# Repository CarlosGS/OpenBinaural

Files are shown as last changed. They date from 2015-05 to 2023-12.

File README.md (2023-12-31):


# OpenBinaural 3D microphone design
Low-cost 3D-printable binaural microphone.  

Project presented at [**OSHWDem 2015**](http://oshwdem.org/) (Open Source Hardware Demonstration in A Coruña, Spain) and [**Maker Faire Bilbao 2015**](http://bilbaomakerfaire.com/meet-the-makers-2015/). First featured in [**Hackaday**](http://hackaday.com/2015/06/28/3d-printing-binaural-microphones/).

Assembly instructions
--
[**Click here for the full assembly instructions**](https://github.com/carlosgs/OpenBinaural/wiki)  

Demo recordings
--
* By [Philippe Benaim](https://www.youtube.com/channel/UCL3Ne8XJYRqAHHRvmHdczcw):
 * Un tour Montgolfière [(link)](https://www.youtube.com/watch?v=H2nlUVNs7Po)
 * Château de Chenonceau Outside [(link)](https://www.youtube.com/watch?v=rT2So4uhhjw)
 * Vacances Aout 2015 [(link)](https://www.youtube.com/watch?v=p6LAYfAAe6M)
* By Carlosgs:
 * Sea shore in A Coruña, Spain [(link)](https://www.youtube.com/watch?v=49GC-DsRlKY)
* If you use the mic, please let me know, I'd love to *hear* about it! :-)

Assembled OpenBinaural microphone:  

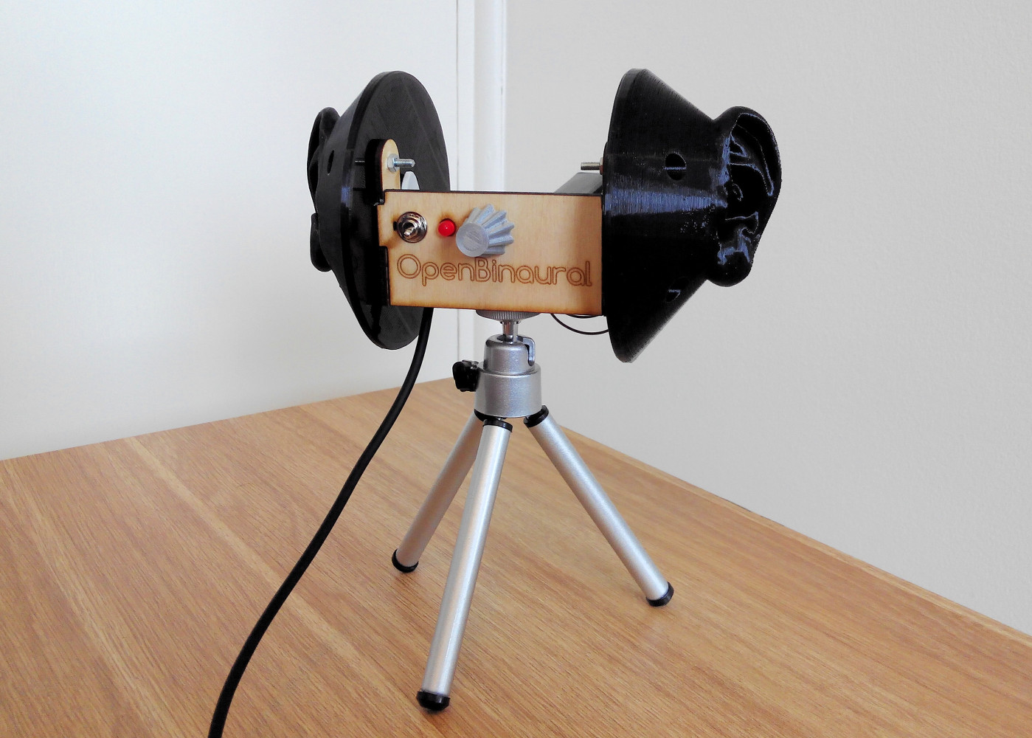
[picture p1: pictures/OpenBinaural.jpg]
  

3D-printable ears  
--
The [left](binaural_mic_left.stl) and [right](binaural_mic_right.stl) ears, and the [potentiometer knob](potentiometer_knob.stl) can be 3D-printed in PLA or ABS. Flexible materials may create more realistic effects!  
The support for the ears can be laser-cut out of 3mm plywood ([DXF file](wood_support.dxf)) or 3D printed ([STL file](wood_support_assembled_simplified.stl)).

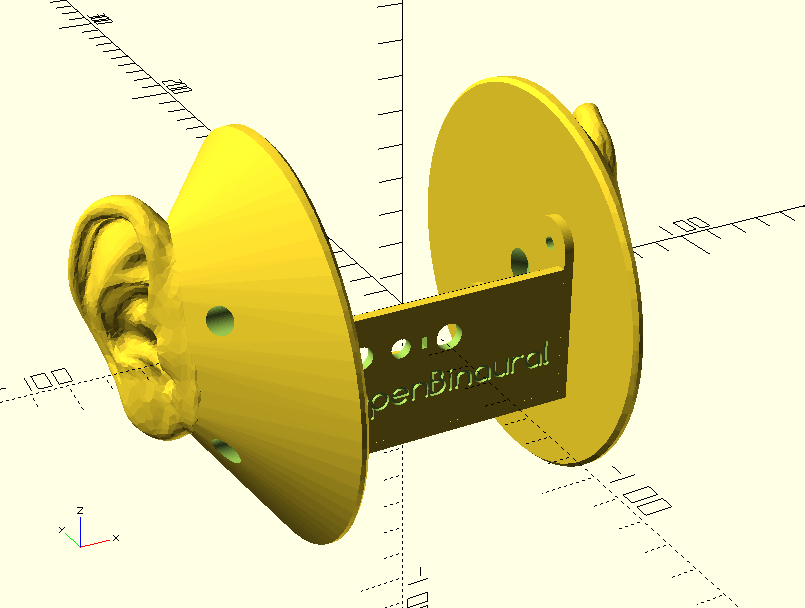
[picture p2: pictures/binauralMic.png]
  

Tripod mount detail:  
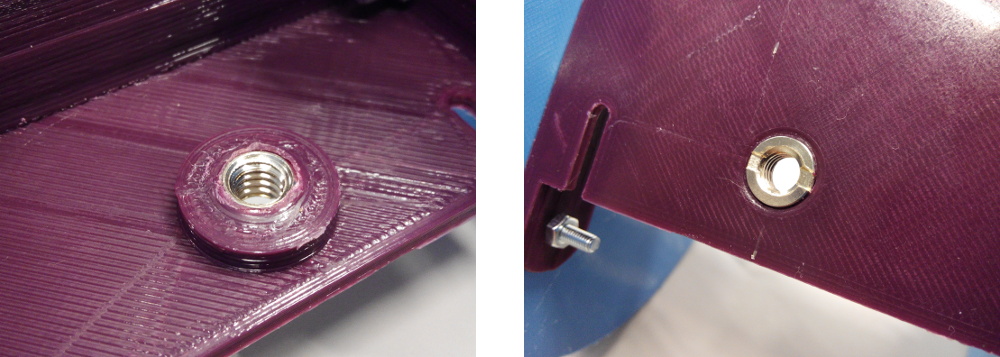
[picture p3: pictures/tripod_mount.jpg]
  
The metal insert can be found in eBay as *1/4" to 3/8" convert screw*  

Electronics  
--

**Note: The amplifier circuit is very outdated and noisy! Instead I recommend connecting the microphone capsules directly to the recorder. See [here](https://github.com/carlosgs/OpenBinaural/wiki#if-you-have-a-gopro-you-dont-need-the-amplifier-circuit) for an example.**

The KiCad sources for the electronics can be found in the [Electronics](Electronics) folder.  
Here are the [schematic](Electronics/stereo_mic_amplifier.pdf) and [layout](Electronics/pictures/stereo_mic_amplifier_layout.png).  
The Gerber files, B/W layout in PDF, and CNC gcode files can be found [here](Electronics/Gerber).  

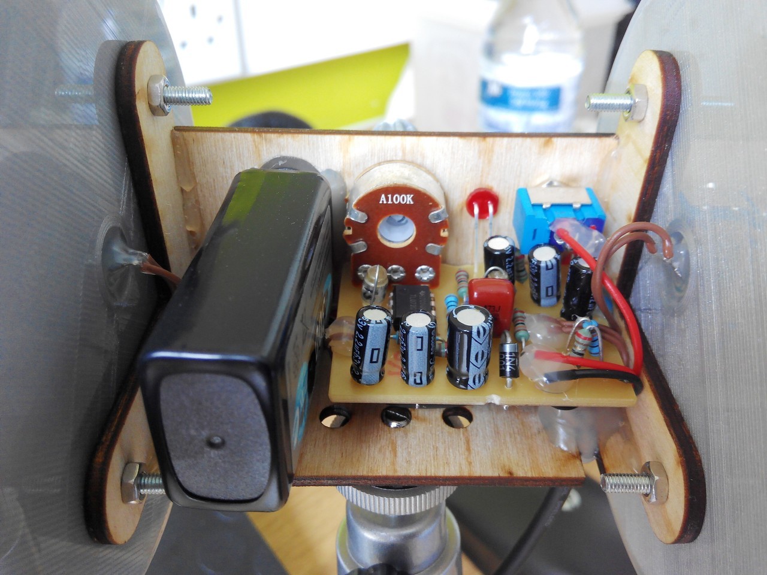
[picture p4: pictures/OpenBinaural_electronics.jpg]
  

Detailed ear canal
--
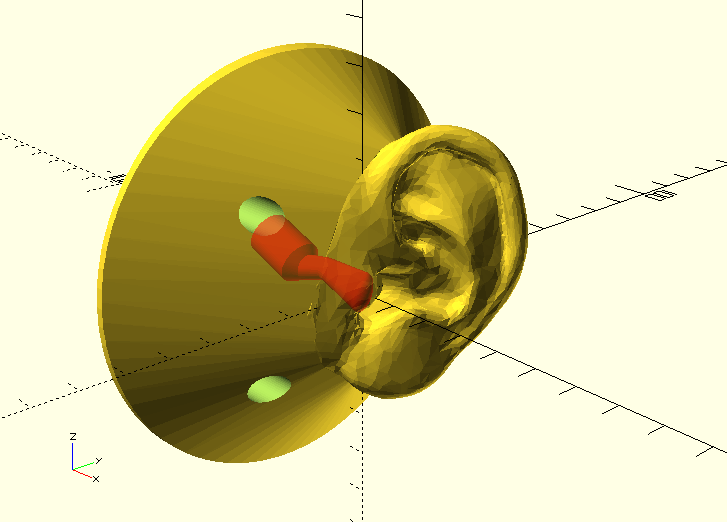
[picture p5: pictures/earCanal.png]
  
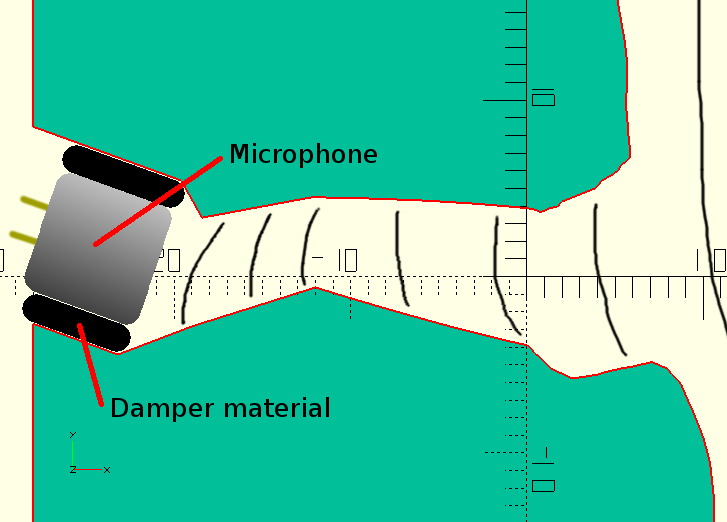
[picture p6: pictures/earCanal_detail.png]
  

Where to buy
--
I currently have no plans to sell this microphone, it has an open license so **anyone can build it or sell it** (as long as they provide attribution and publish their modifications as open too).  
Please refer to the following links if you just need a binaural microphone that works out of the box:  

- [**3Dio**](https://3diosound.com/)
- [**SR3D**](https://www.sr3d.co.uk/), [**Ebay**](https://www.ebay.co.uk/str/sr3dbinauralmicrophones)

Acknowledgments  
--
* The awesome ear model was designed by **Jonathan March**:  
<http://www.thingiverse.com/thing:499001>  
For this project, the STL was modified with [FreeCAD](http://freecadweb.org/) and [Blender](http://www.blender.org/)  

* Great inspiration was taken from [**3Dio**](http://3diosound.com/).
If you need professional quality & high-performance, check out their Free Space microphones!  

* The potentiometer knob model is derived from **John Ridley's**: <https://www.youmagine.com/designs/knob-for-potentiometer-parametric>

* I want to thank [**Imperial College Advanced Hackspace**](http://icah.org.uk/) and [**Imperial College Robotics Society**](http://icrobotics.co.uk/) for providing the infrastructure (tools, 3D printers, laser cutters & material resources) that made this project possible. The community that has grown upon them is just amazing.  

* Also thanks to Mr Rodrigo García Saura for sourcing the 1/4" to 3/8" convert screw for the tripod mount  

Author & license  
--
Author: Carlos Garcia Saura (<https://github.com/CarlosGS/>)  
License: CC-BY-SA (<http://creativecommons.org/licenses/by-sa/4.0/>)  

Please cite as:
--

Latex / Bibtex citation:

```bibtex
@misc{garciasaura2015binaural,
  author = {Garcia-Saura, Carlos},
  title = {Open Binaural 3D microphone design},
  publisher = {GitHub},
  year = {2015},
  doi = {10.5281/ZENODO.10446511},
  url = {https://doi.org/10.5281/ZENODO.10446511}
}
```

APA style citation:

- García-Saura, C. (2015). Open Binaural 3D microphone design. GitHub. https://doi.org/10.5281/ZENODO.10446511

Also check out my previous work _"3D Video with Binaural Audio"_:

- García-Saura, C. (2011). Vídeo en 3D con Sonido Binaural. Congreso del XXIV Certamen Jóvenes Investigadores INJUVE, CEULAJ Málaga. INJUVE. https://doi.org/10.5281/ZENODO.10445722

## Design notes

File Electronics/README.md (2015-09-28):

# Stereo microphone amplifier

Stereo microphone amplifier circuit with gain control.  

The circuit has been tested with the POM-5238P-R microphone capsules:  
<http://www.puiaudio.com/product-detail.aspx?categoryId=4&partnumber=POM-5238P-R>  

CNC manufacture files (gerbers, FlatCAM project & gcodes) are available in the [Gerber](Gerber) folder.  

Assembly instructions
--
[**Click here for the full assembly instructions**](https://github.com/carlosgs/OpenBinaural/wiki)  

Pictures  
--
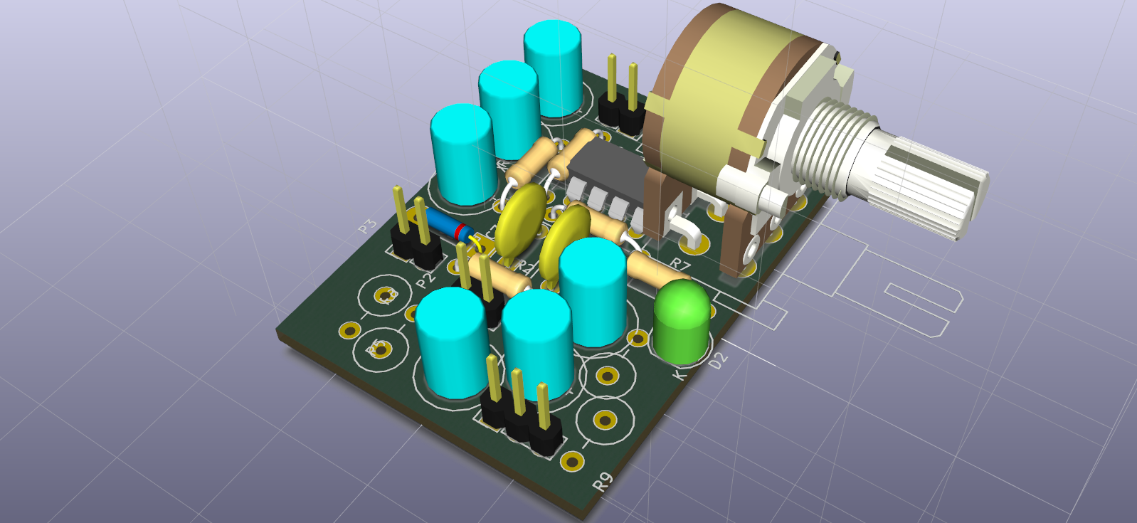
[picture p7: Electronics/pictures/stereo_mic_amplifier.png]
  
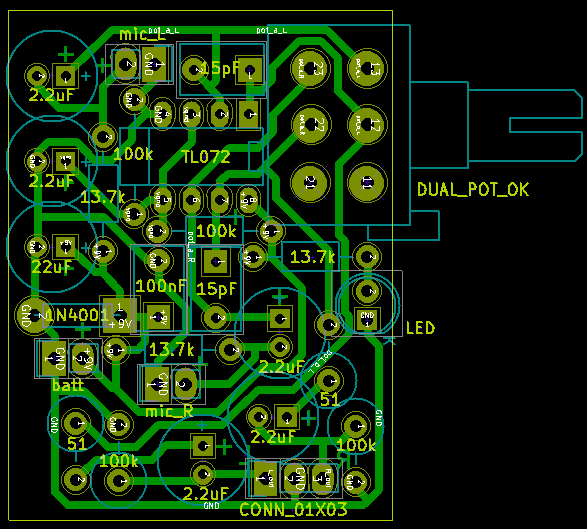
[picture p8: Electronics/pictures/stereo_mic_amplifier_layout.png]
  
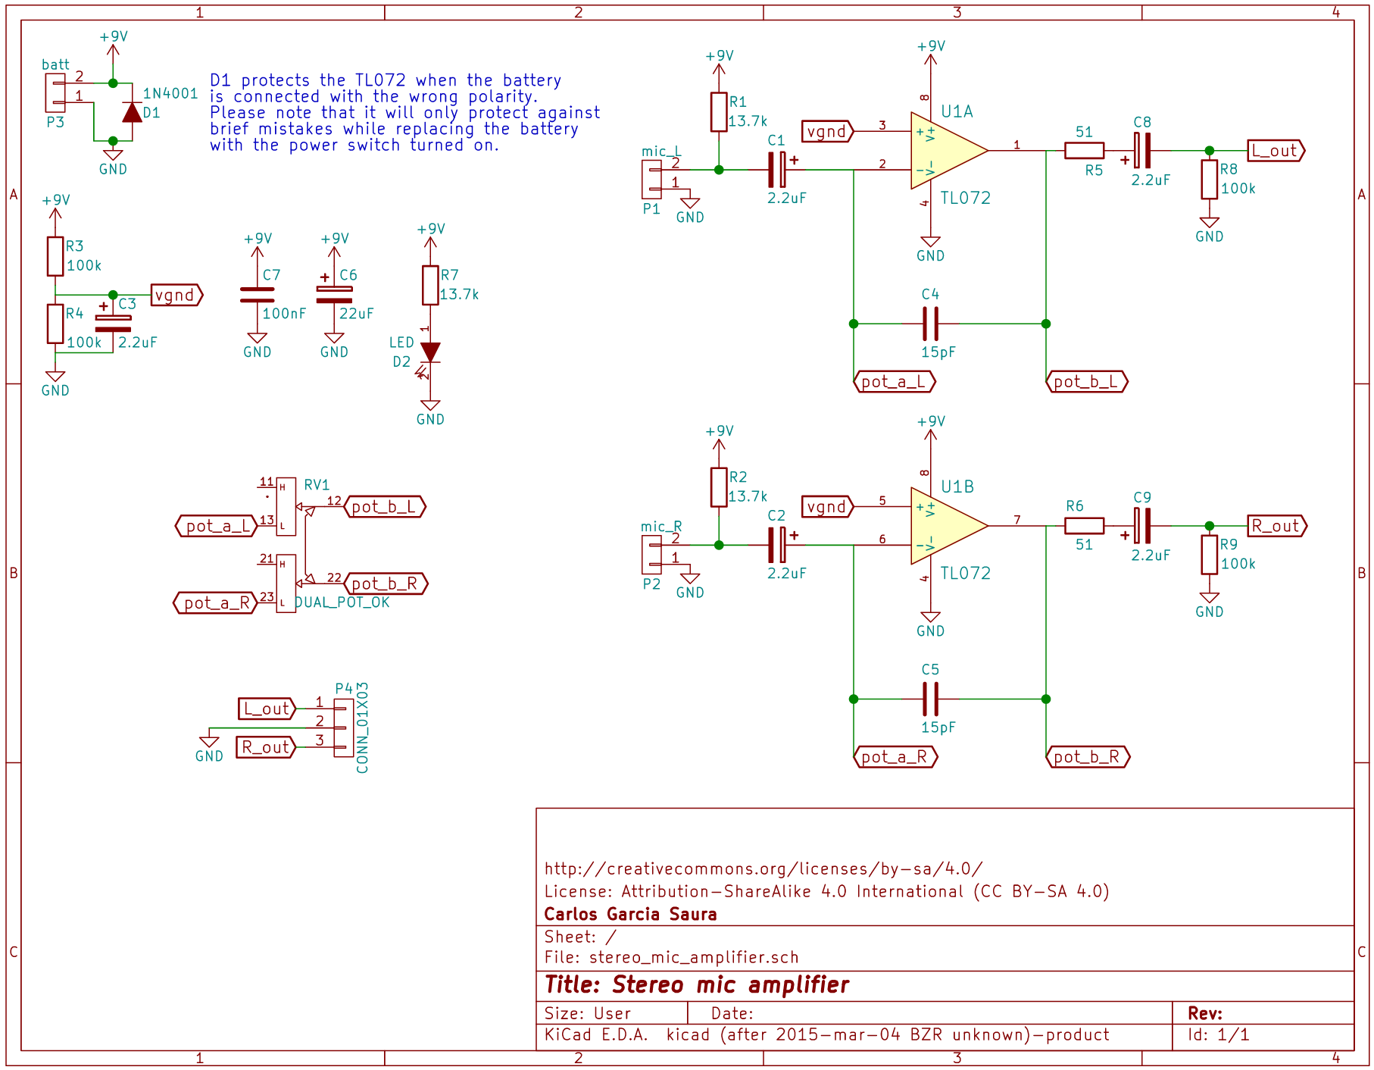
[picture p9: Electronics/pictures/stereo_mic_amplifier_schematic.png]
  
[Download the schematic in PDF](stereo_mic_amplifier.pdf)  

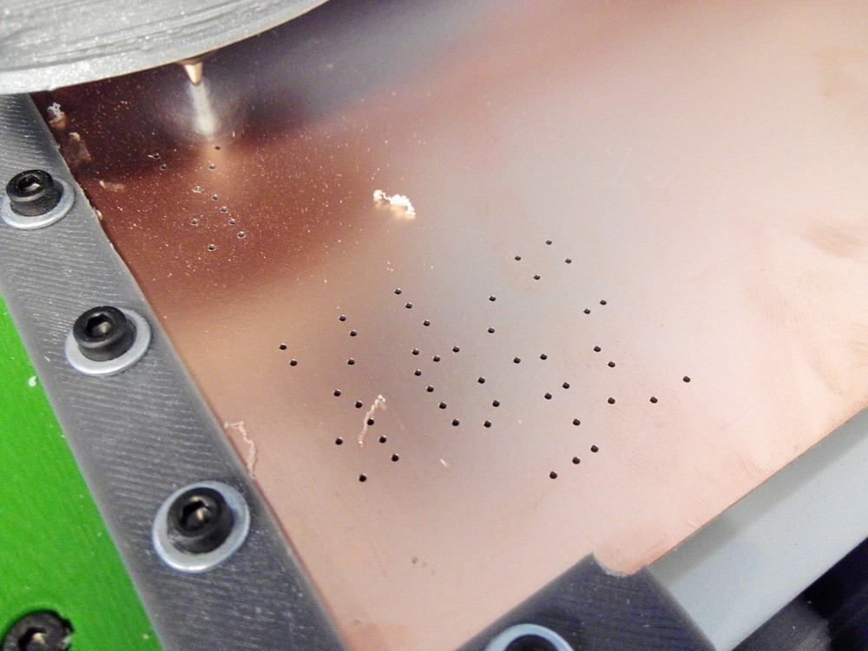
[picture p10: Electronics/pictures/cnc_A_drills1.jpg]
  
Aprox milling time for 0.8mm drill: 4 minutes  

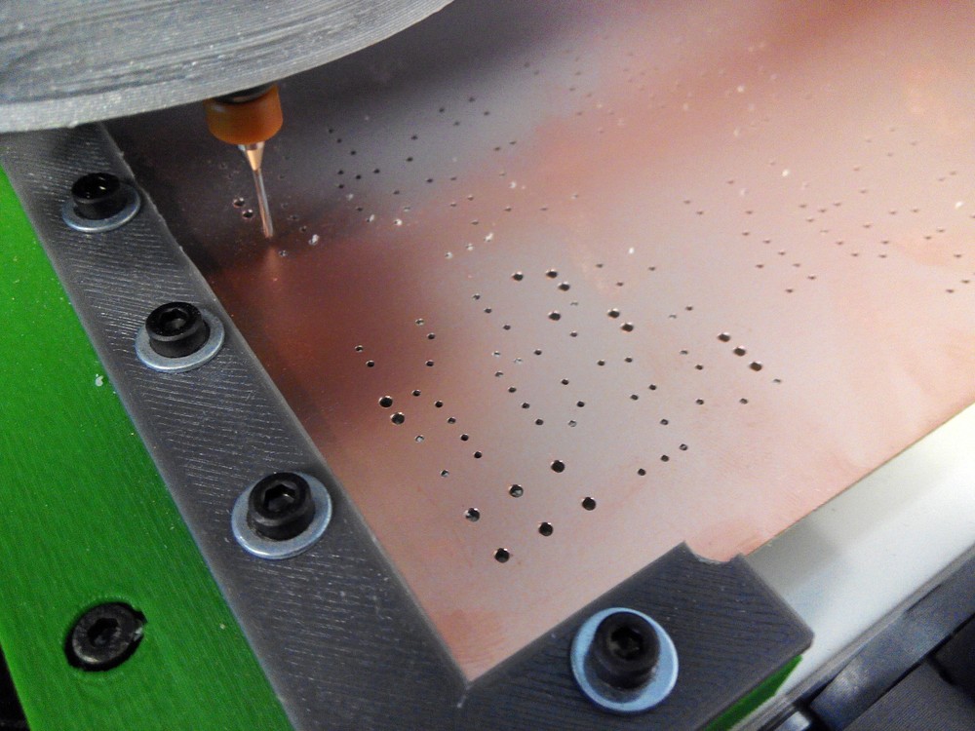
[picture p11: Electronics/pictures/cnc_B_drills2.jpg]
  
Aprox milling time for 1.2mm drill: 2 minutes  

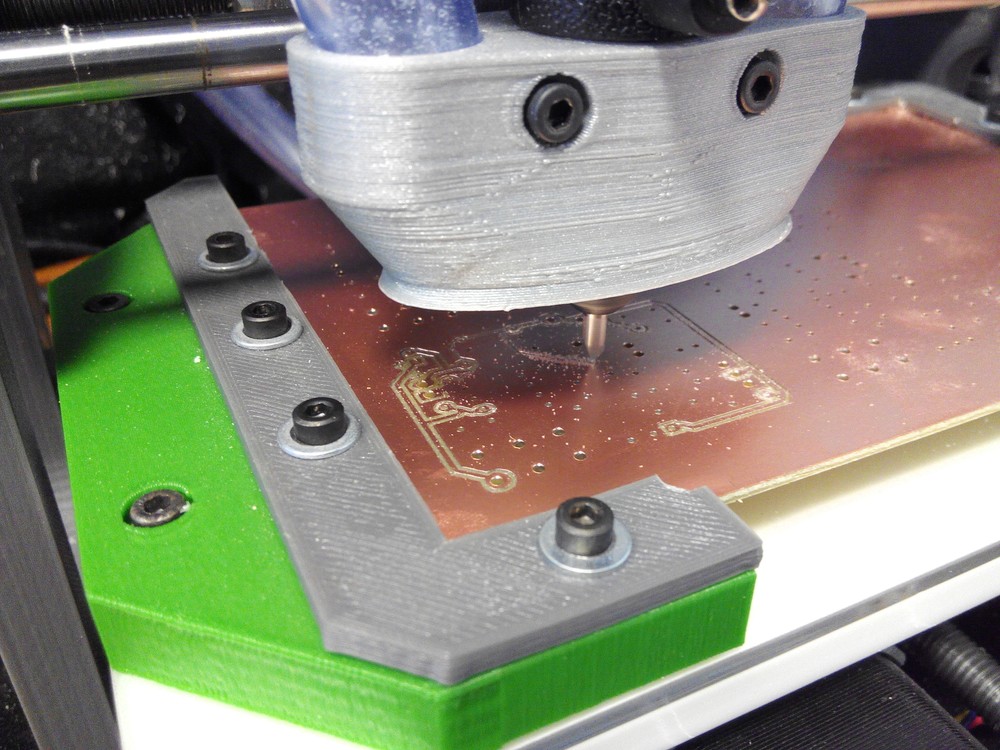
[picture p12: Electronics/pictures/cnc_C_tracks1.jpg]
  

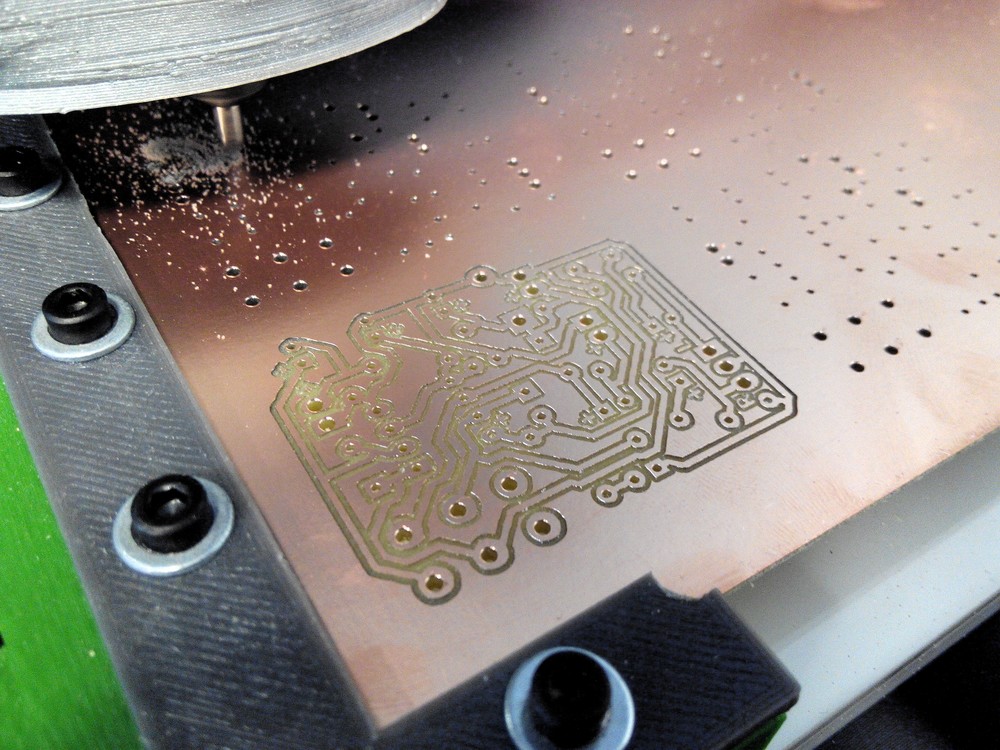
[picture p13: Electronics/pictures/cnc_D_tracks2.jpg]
  
Aprox milling time for 0.3mm copper etching: 20 minutes  

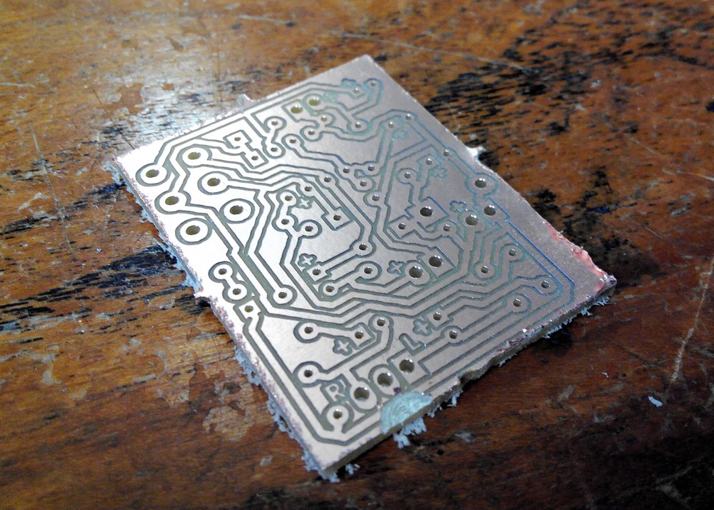
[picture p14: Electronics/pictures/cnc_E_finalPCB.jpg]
  
Aprox milling time for 2mm edges routing: 3 minutes  

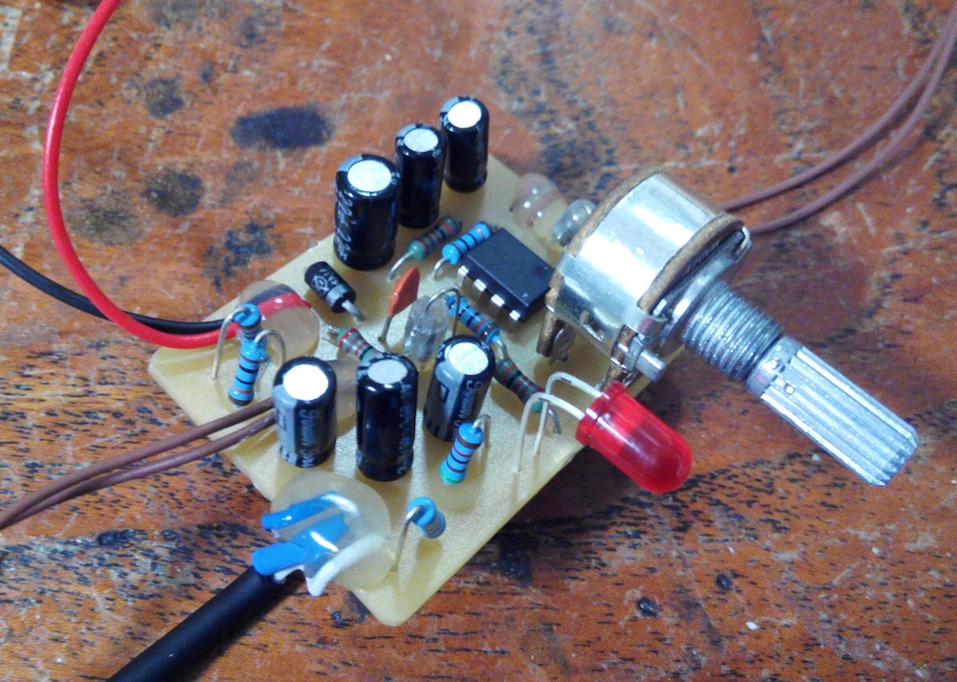
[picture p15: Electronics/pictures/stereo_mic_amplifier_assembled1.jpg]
  
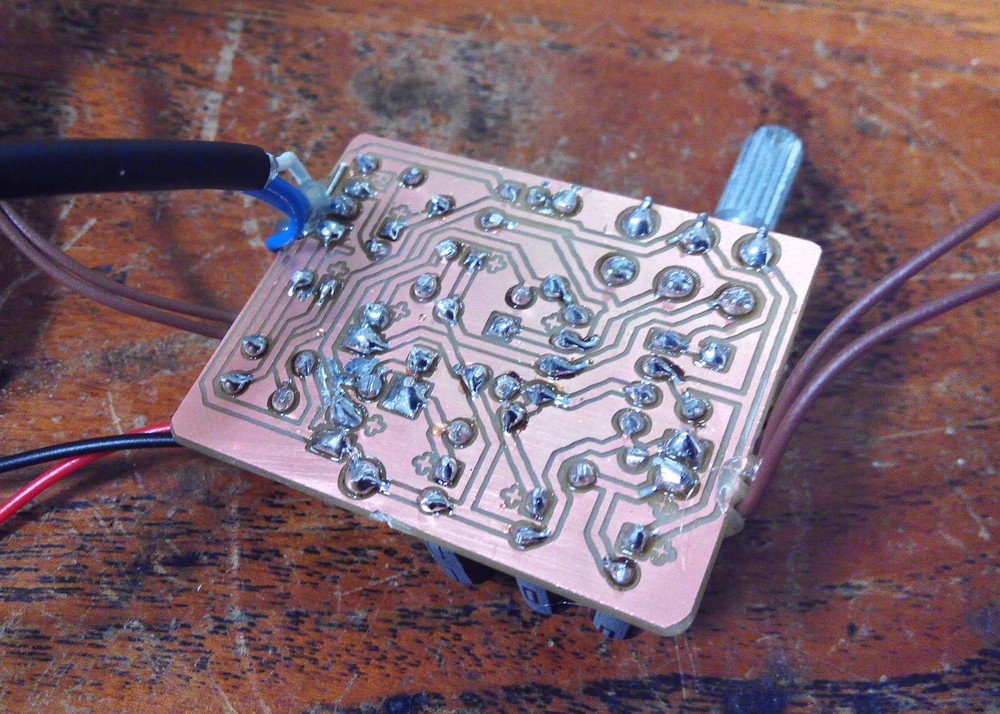
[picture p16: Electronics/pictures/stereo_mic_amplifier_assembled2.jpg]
  

Acknowledgments  
--
This circuit is a derivation from the following -very useful- Texas Instruments guide:  
[Single-Supply, Electret Microphone Preamplifier Reference Design](http://www.ti.com/tool/TIPD181) by John Caldwell  
Gain control is achieved by replacing R2 (75k) with a 100k dual potentiometer.  

Author & license  
--
Author: Carlos Garcia Saura (<http://www.carlosgs.es>)  
License: CC-BY-SA (<http://creativecommons.org/licenses/by-sa/4.0/>)

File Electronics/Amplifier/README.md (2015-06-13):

The schematic, layout & cnc manufacture files can be found in the <Amplifier> folder.  

Using the TI example application as a base, we made a stereo circuit and control the gain by replacing R2 (75k) with a 100k dual potentiometer.

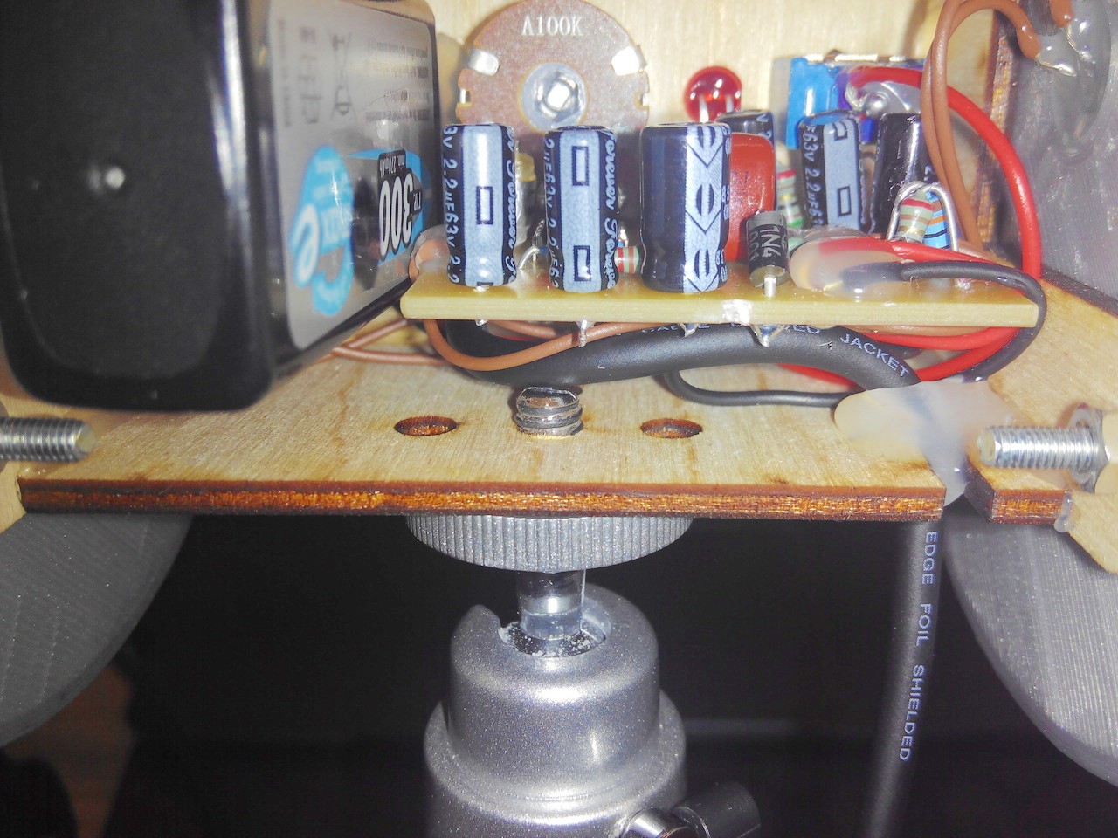
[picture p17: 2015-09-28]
pictures/OpenBinaural_electronics_2.jpg

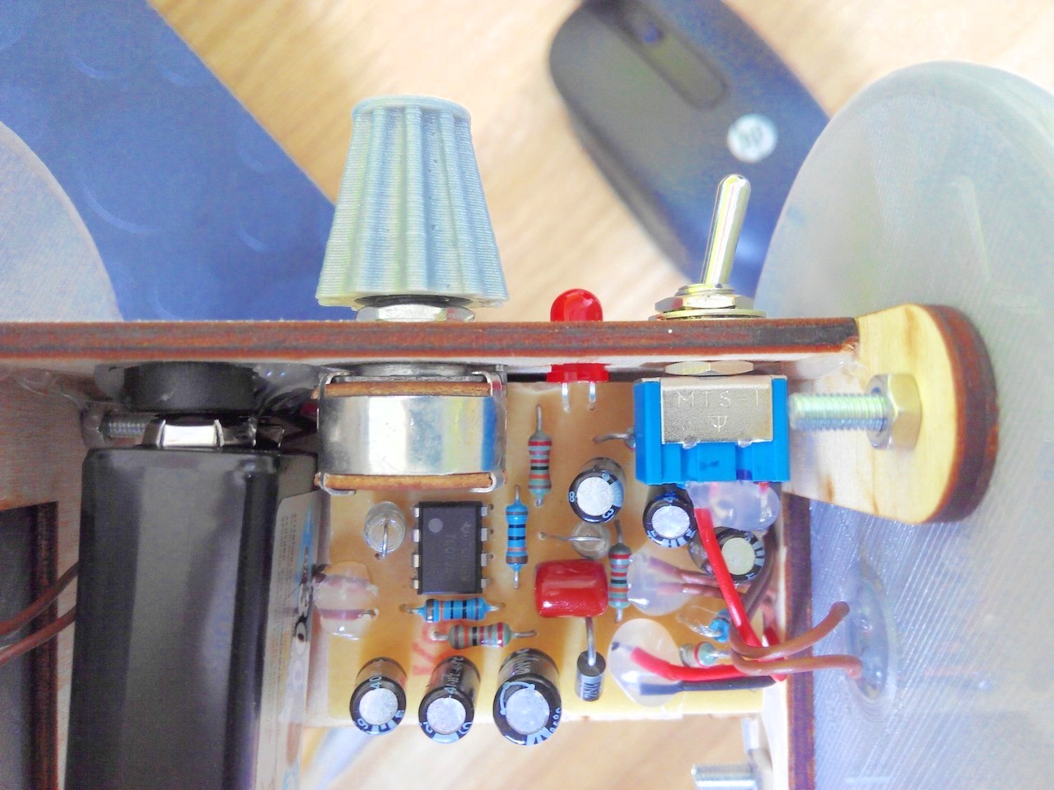
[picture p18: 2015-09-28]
pictures/OpenBinaural_electronics_3.jpg

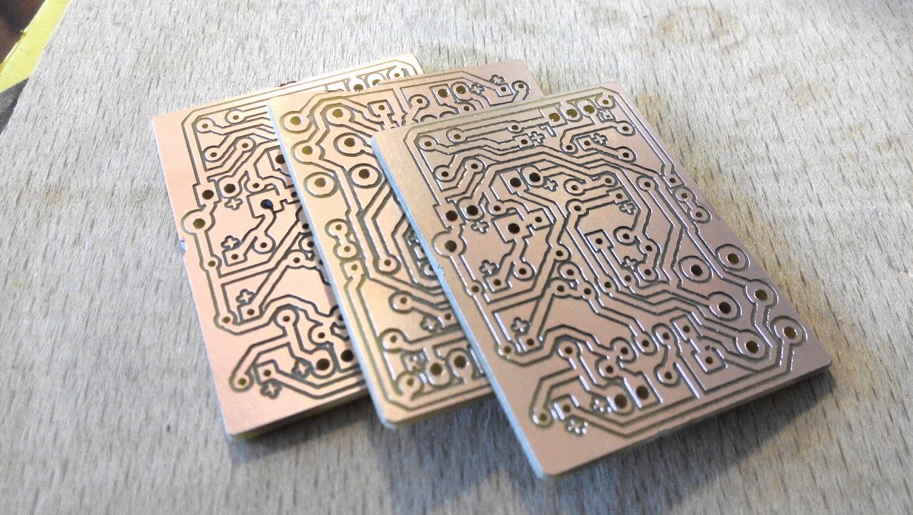
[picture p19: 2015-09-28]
Electronics/pictures/stereo_mic_amp_pcbs.jpg

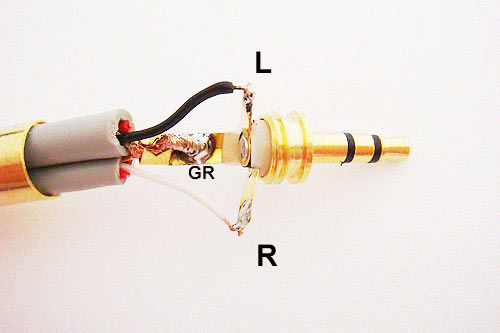
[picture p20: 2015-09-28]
Electronics/pictures/jack_connector.jpg

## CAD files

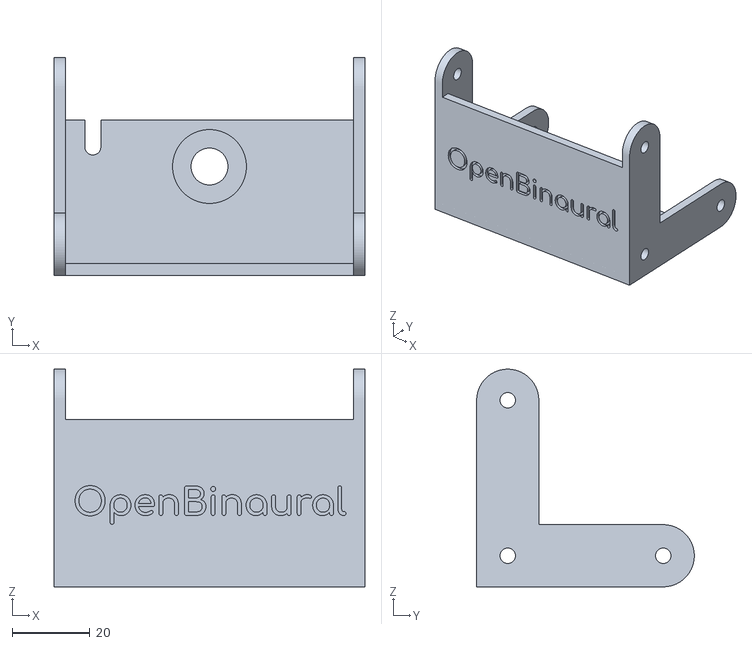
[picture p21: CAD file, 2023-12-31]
wood_support_assembled_simplified.stl
80.0 x 56.0 x 56.0

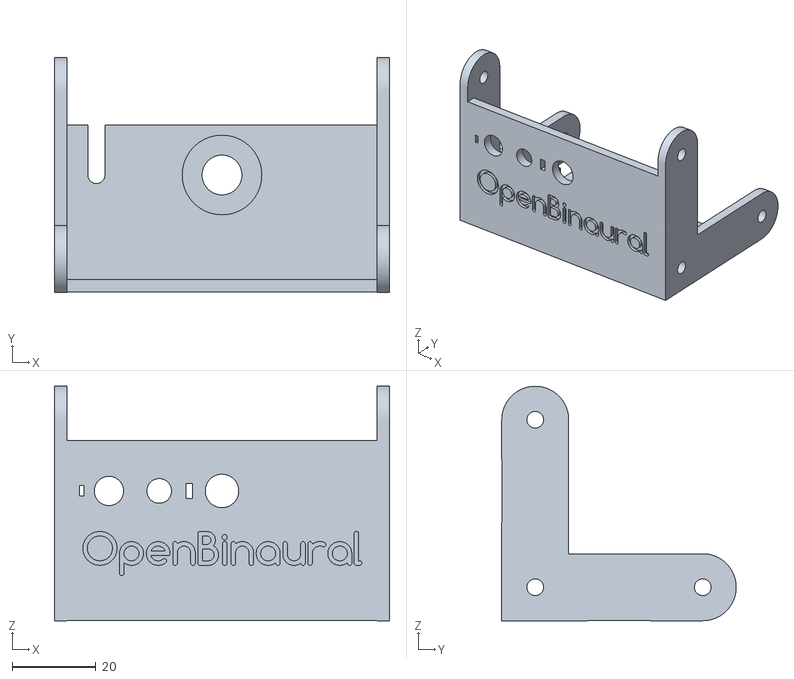
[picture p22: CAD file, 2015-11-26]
wood_support_assembled.stl
80.0 x 56.0 x 56.0

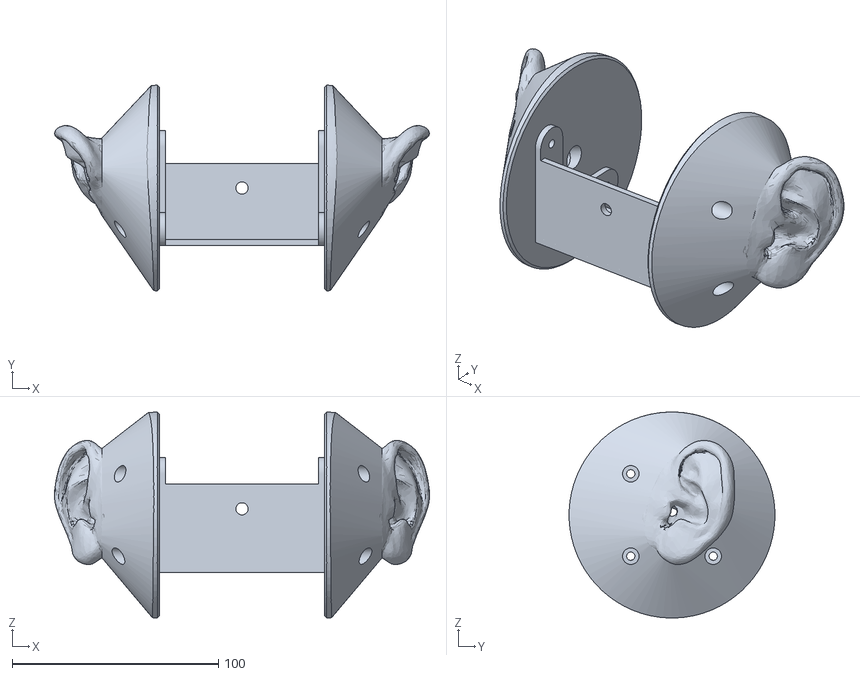
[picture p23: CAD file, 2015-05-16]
binaural_mic_assembled.stl
182.0 x 99.8 x 99.9

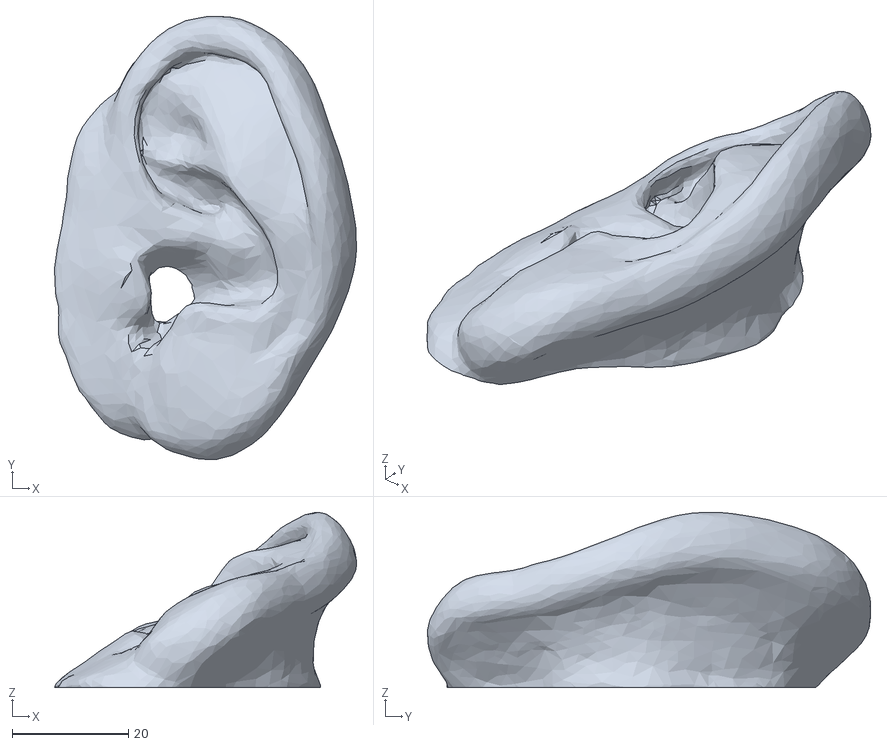
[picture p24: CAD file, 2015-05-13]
source_code/ear_left.stl
52.0 x 76.2 x 30.2

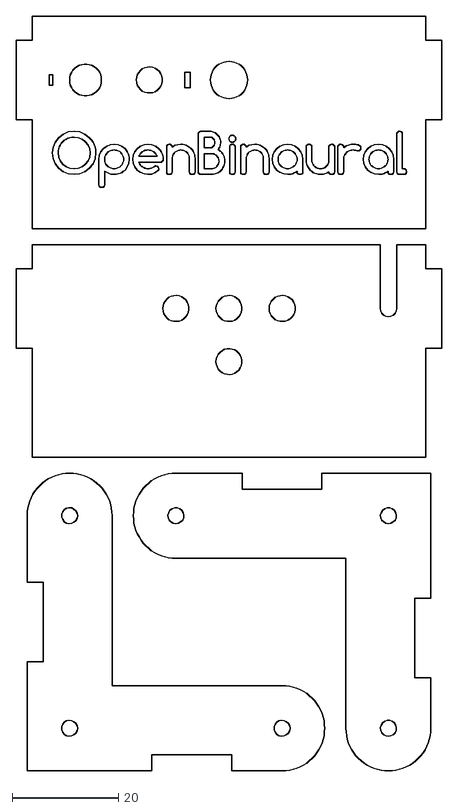
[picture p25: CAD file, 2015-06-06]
without_metal_insert/wood_support.dxf
80.0 x 142.0

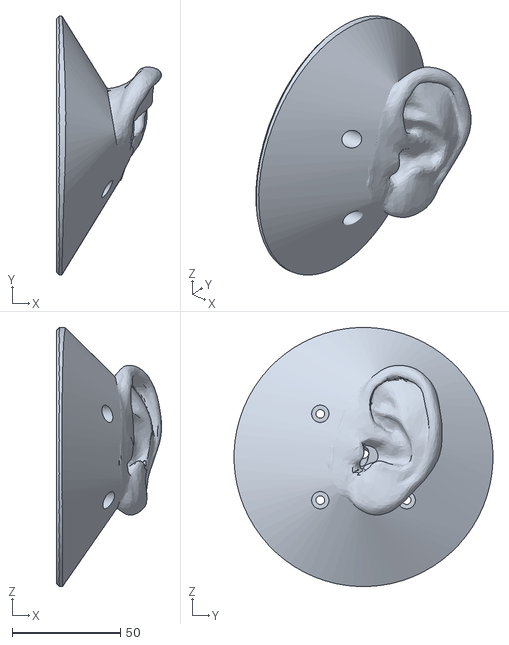
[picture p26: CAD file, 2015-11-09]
binaural_mic_left.stl
48.6 x 119.8 x 119.9

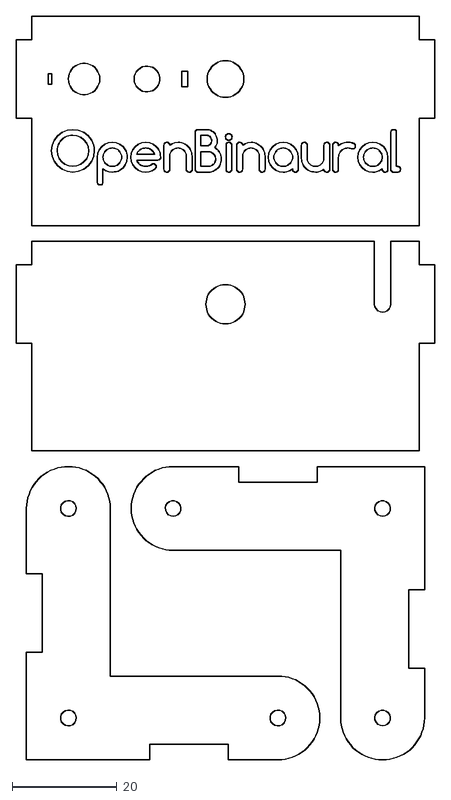
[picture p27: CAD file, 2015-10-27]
wood_support.dxf
80.0 x 142.0

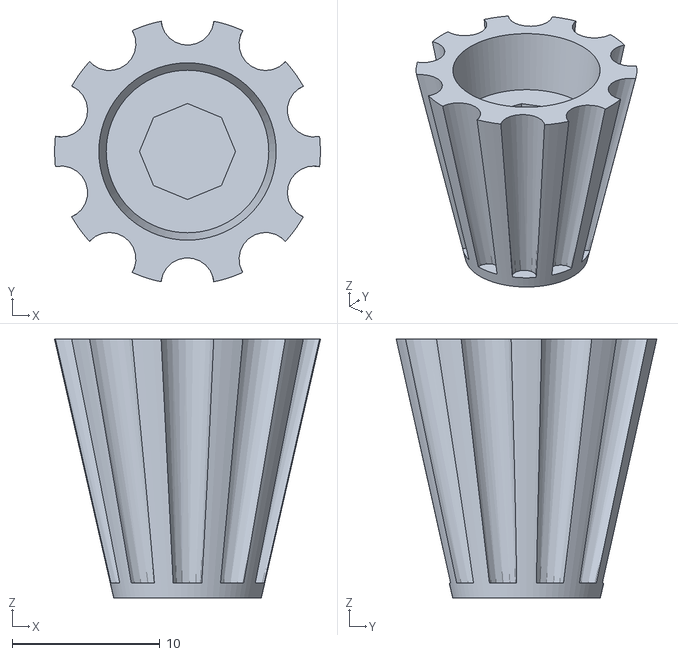
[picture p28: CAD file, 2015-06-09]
potentiometer_knob.stl
18.0 x 17.6 x 17.5

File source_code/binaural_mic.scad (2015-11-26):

// 3D-printable Binaural Microphone
//
// by Carlos Garcia Saura (http://www.carlosgs.es)
// License: CC-BY-SA (http://creativecommons.org/licenses/by-sa/4.0/)
//
// The awesome ear model was designed by Jonathan March
// http://www.thingiverse.com/thing:499001
// http://professorgreenscreen.com/


// Increase the resolution of default shapes
$fa = 5; // Minimum angle for fragments [degrees]
$fs = 0.5; // Minimum fragment size [mm]

ear_rotation = -15;
ear_vertical_rotation = 10;

ear_base_diameter = 120;
ear_canal_len_1 = 12;
ear_canal_len_2 = 8;
ear_canal_diam_1 = 5;
ear_canal_diam_2 = 6;
ear_canal_bump_height = 2;

mic_diam = 11;
mic_len = 8;
mic_transition_len = 1.5;



screw_head_diam = 8;
screw_diam = 4;
screw_holder_thickness = 5;

screw_separation = 40;

ear_scale = 68/73.54;

ear_separation = 136;



tripod_hole_diam = 9.5;// Use 5.9 for self-tapping tripod version

wood_thickness = 3;


wood_radius = screw_head_diam/2 + 4;

font = "Comfortaa:style=Bold";
brand = "OpenBinaural";
letter_size = 7.5;



ear_base_thickness = ear_canal_len_1 + ear_canal_len_2 + mic_len;
ear_base_separation = ear_separation-ear_base_thickness*2;
wood_length = ear_base_separation;


module screw_hole() {
    rotate([0,90,0]) cylinder(r=screw_diam/2,h=ear_base_thickness);
    translate([screw_holder_thickness,0,0])
        rotate([0,90,0]) cylinder(r=screw_head_diam/2,h=ear_base_thickness-screw_holder_thickness);
}

module ear_left() {
    rotate([0,90,0])
        rotate([0,0,90+3+ear_rotation])
            scale(ear_scale)
                translate([8,10,-3.01])
                    import("ear_left.stl");
}



module ear_left_full() {
    difference() {
        union() {
            rotate([0,0,ear_vertical_rotation]) ear_left();
            intersection() {
                rotate([0,-90,0])
                    hull() {
                    rotate([ear_vertical_rotation,0,0]) linear_extrude(height=0.01,center=true)
                        projection(cut=true)
                            rotate([0,90,0]) ear_left();
                    translate([0,0,ear_base_thickness])
                        cylinder(r=ear_base_diameter/2+4,h=0.01,center=true);
                    }
                // Define the ear circular base
                translate([-ear_base_thickness,0,0])
                    sphere(r=ear_base_diameter/2);
                // Bevel
                translate([-ear_base_thickness+ear_base_diameter/2,0,0])
                    sphere(r=ear_base_diameter/2+24);
            }
        }
        
        // Ear canal
        difference() {
            union(){
                // Curved inner ear
                //translate([0,2,0.5])
                //    scale([0.5,1,1])
                //        sphere(r=8/2);
                hull() {
                    rotate([ear_rotation,0,0])
                        scale([0.5,0.5,1])
                            sphere(r=9/2);
                    translate([-ear_canal_len_1,0,ear_canal_bump_height])
                        sphere(r=ear_canal_diam_1/2);
                }
                hull() {
                    translate([-ear_canal_len_1,0,ear_canal_bump_height])
                        sphere(r=ear_canal_diam_1/2);
                    translate([-ear_canal_len_1-ear_canal_len_2,0,0])
                        sphere(r=ear_canal_diam_2/2);
                }
                translate([-ear_canal_len_1-ear_canal_len_2,0,0])
                        rotate([0,20,0]) {
                            // Transition
                            hull() {
                                sphere(r=ear_canal_diam_2/2);
                                translate([-mic_transition_len,0,0])
                                    rotate([0,90,0]) cylinder(r=mic_diam/2,h=0.01);
                            }
                            // Hole for the microphone
                            translate([-mic_transition_len,0,0])
                                rotate([0,-90,0]) cylinder(r=mic_diam/2, h=mic_len*1.5);
                            // Bevel
                            //translate([-mic_len,0,0])
                            //    rotate([0,-20,0])
                            //        translate([-3,0,0])
                            //            sphere(r=mic_diam/2+1.5);
                        }
            }
            // Bump to limit microphone depth
            //translate([-ear_canal_len_1-ear_canal_len_2,0,mic_diam/2+0.3])
            //    rotate([90,0,0]) cylinder(r=1.5/2,h=mic_diam,center=true);
        }
        
        translate([-ear_base_thickness-0.1,0,0]) {
            translate([0,-screw_separation/2,screw_separation/2])
                screw_hole();
            translate([0,-screw_separation/2,-screw_separation/2])
                screw_hole();
            translate([0,screw_separation/2,-screw_separation/2])
                screw_hole();
        }
    }
}

module ear_right_full() {
    mirror([1,0,0])
        ear_left_full();
}






// Draw the canal section
//!projection(cut=true) rotate([-90,0,0]) ear_left_full();

// Draw the head (assuming it is a sphere)
//#sphere(r=140/2);

translate([ear_separation/2,0,0])
    ear_left_full();
translate([-ear_separation/2,0,0])
    ear_right_full();






// Wood parts

module wood_support_left(laser_cutter_offset=0) {
    translate([ear_base_separation/2,0,0])
        rotate([0,-90,0])
            difference() {
                union() {
                    hull() {
                        translate([screw_separation/2,-screw_separation/2,0])
                            cylinder(r=wood_radius,h=wood_thickness);
                        translate([-screw_separation/2,-screw_separation/2,wood_thickness/2])
                                cube([wood_radius*2,wood_radius*2,wood_thickness],center=true);
                    }
                    hull() {
                        translate([-screw_separation/2,-screw_separation/2,wood_thickness/2])
                                cube([wood_radius*2,wood_radius*2,wood_thickness],center=true);
                        translate([-screw_separation/2,screw_separation/2,0])
                                cylinder(r=wood_radius,h=wood_thickness);
                    }
                }
                // Screw holes
                translate([screw_separation/2,-screw_separation/2,0])
                    cylinder(r=screw_diam/2-laser_cutter_offset,h=wood_thickness*4,center=true);
                translate([-screw_separation/2,-screw_separation/2,0])
                    cylinder(r=screw_diam/2-laser_cutter_offset,h=wood_thickness*4,center=true);
                translate([-screw_separation/2,screw_separation/2,0])
                    cylinder(r=screw_diam/2-laser_cutter_offset,h=wood_thickness*4,center=true);
                // Wood "interlock" slots
                translate([wood_thickness,-screw_separation/2-wood_radius,0])
                    cube([15,wood_thickness*2,wood_thickness*2],center=true);
                translate([-screw_separation/2-wood_radius,0,0])
                    cube([wood_thickness*2,15,wood_thickness*2],center=true);
            }
}

module wood_support_right(laser_cutter_offset=0) {
    mirror([1,0,0])
        wood_support_left(laser_cutter_offset);
}
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

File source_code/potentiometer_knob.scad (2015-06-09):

// Based on:
// https://www.youmagine.com/designs/knob-for-potentiometer-parametric
// By John Ridley

// Increase the resolution of default shapes
$fa = 5; // Minimum angle for fragments [degrees]
$fs = 0.5; // Minimum fragment size [mm]

od = 18;
odt = 10;
mainh = 0;
th = 17.5-mainh;

// knurling
kd = 7/2;
kn = 10;

shaftd = 6.5;

rotate([180,0,0])
difference()
{
    translate([0,0,0.01])
	union()
	{
		cylinder(d=od, h=mainh);
		translate([0,0,mainh])
		cylinder(d1=od, d2=odt, h=th);
	}

	// knurling
	for (x=[0:kn])
        rotate([0,0,x * (360/kn)])
            translate([0,od/2,0])
                hull() {
                    //rotate([10,0,0]) cylinder(d1=kd, d2=kd, h=mainh+th-1);
                    cylinder(d=2*od/kn, h=0.01);
                    translate([0,(odt-od)/2,mainh+th-1])
                        cylinder(d=2*odt/kn, h=0.01);
                }

	// shaft hole
	cylinder(d=shaftd, h=mainh+th - 1.5, $fn = 8);

	// relief at bottom
	cylinder(d1=12,d2=od - kd*2, h=5);

}

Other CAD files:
without_metal_insert/wood_support_assembled.stl
binaural_mic_right.stl
source_code/binaural_mic_simplified.scad

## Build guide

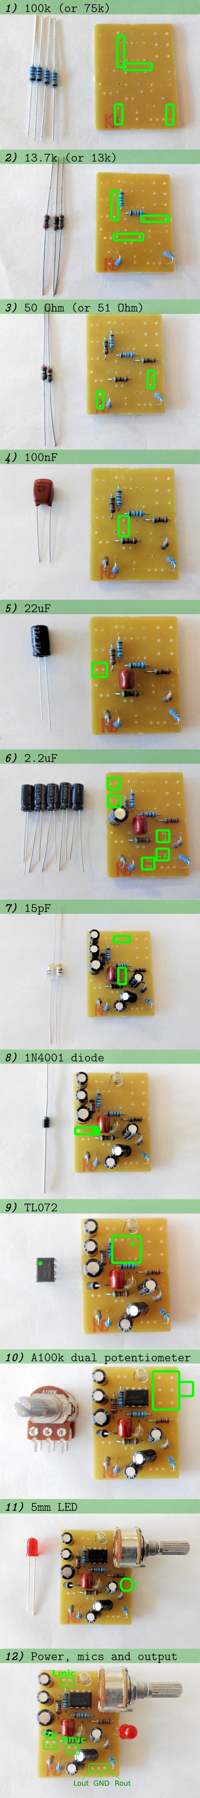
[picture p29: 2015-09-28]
Electronics/pictures/stereo_mic_amplifier_assembly_steps.jpg

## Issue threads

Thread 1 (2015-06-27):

Tripod support is not robust enough

carlosgs, 2015-06-27:
Could we have a metal insert that doesn't wear out as fast as the wood?
Maybe with a standard nut with the tripod screw diameter?

carlosgs, 2015-11-10:
Latest version includes the metal insert (though there is no solution yet for the laser cutted parts).

Closed 2015-11-10.

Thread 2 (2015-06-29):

The diodes are reversed in the schematic

carlosgs, 2015-06-29:
TO-DO: Update the schematic (include a note explaining the power supply short-circuit protection)

Thanks go to Florian for spotting it!!

"Hi,
I saw your binaural microphone project on Hackaday and had a look at your
amplifier schematic.
It seems that the diodes D1 and D2 are connected in the wrong orientation,
the supply is shorted over D1 and the Power LED D2 will not light up.
(https://github.com/carlosgs/OpenBinaural/blob/master/Electronics/stereo_mic_amplifier.pdf)
Some months ago the KICAD guys switched their diode pin numbering in the
libraries, maybe you have used an older schematic with these new library
symbols?
And I don't understand the placement of D1, you want to just short the power
supply lines over the diode if the polarity is wrong?
Regards
Florian"

Closed 2015-07-29.

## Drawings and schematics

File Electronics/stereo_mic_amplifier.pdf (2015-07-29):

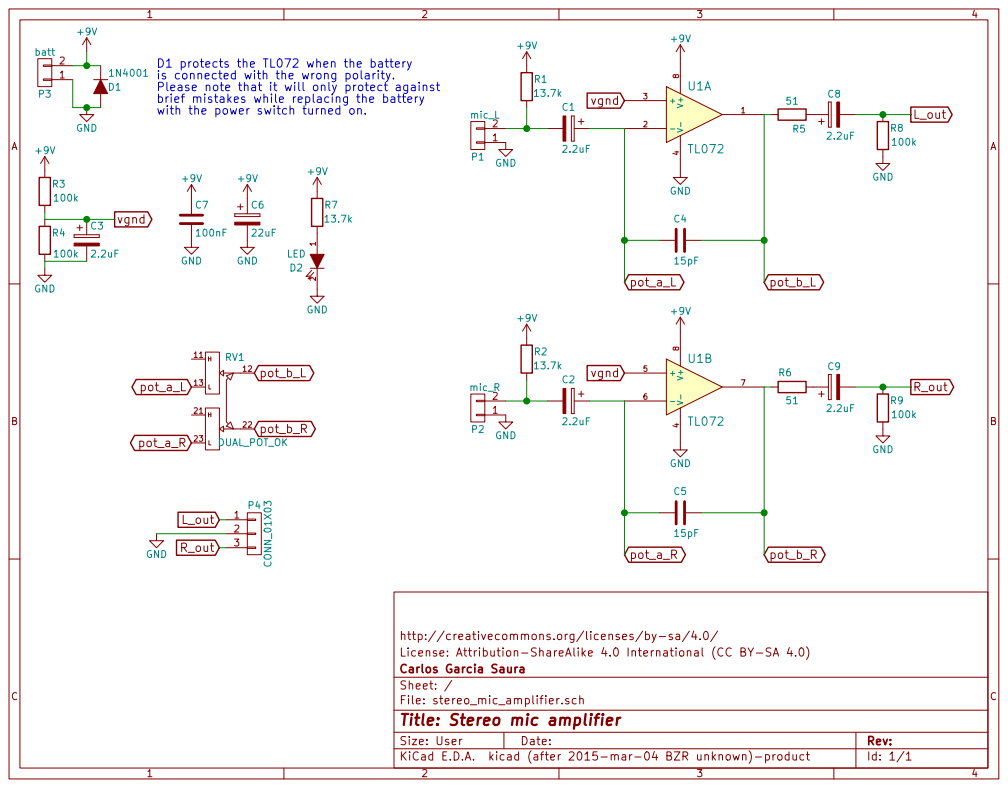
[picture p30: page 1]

is connected with the wrong polarity.
Please note that it will only protect against
brief mistakes while replacing the battery
with the power switch turned on.

License: Attribution-ShareAlike 4.0 International (CC BY-SA 4.0)
File: stereo_mic_amplifier.sch Sheet: / Carlos Garcia Saura

Id: 1/1 Title: Stereo mic amplifier

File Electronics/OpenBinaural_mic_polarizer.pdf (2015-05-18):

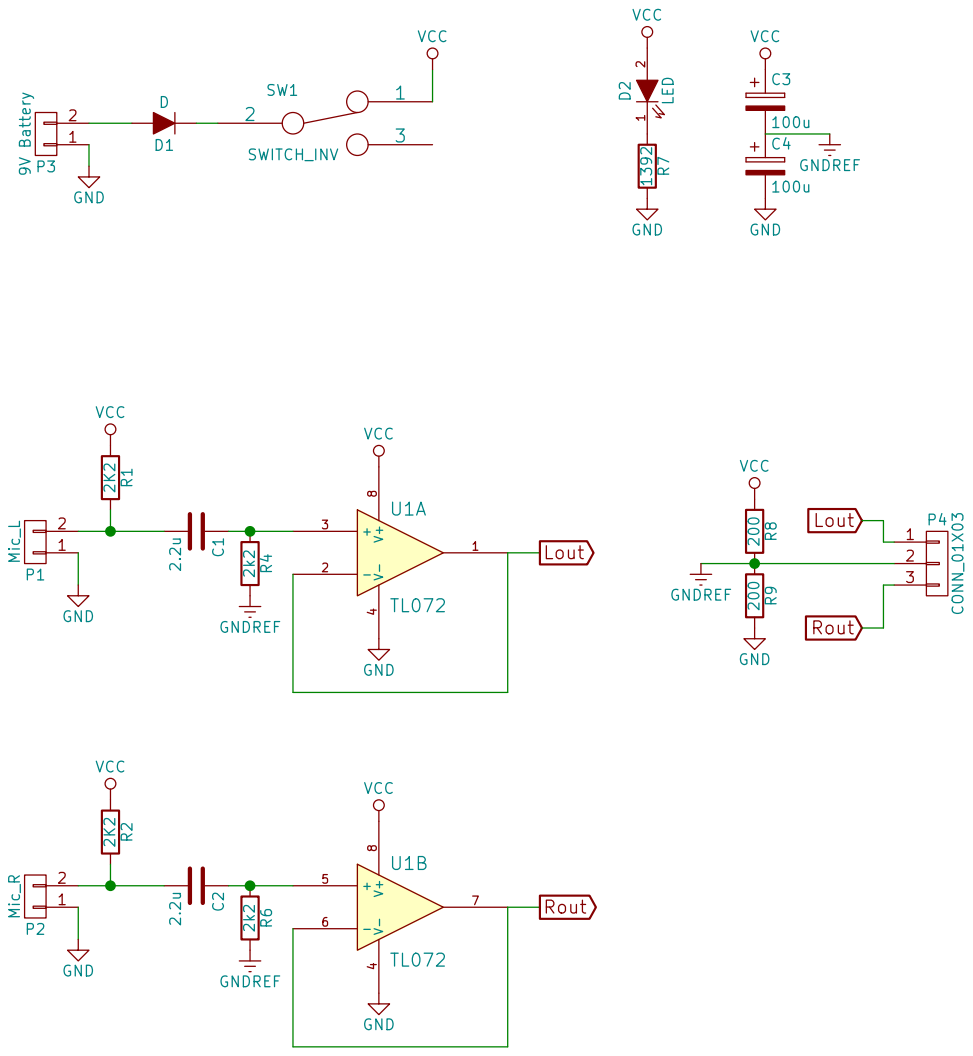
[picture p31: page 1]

VCC GNDREF GNDREF GNDREF

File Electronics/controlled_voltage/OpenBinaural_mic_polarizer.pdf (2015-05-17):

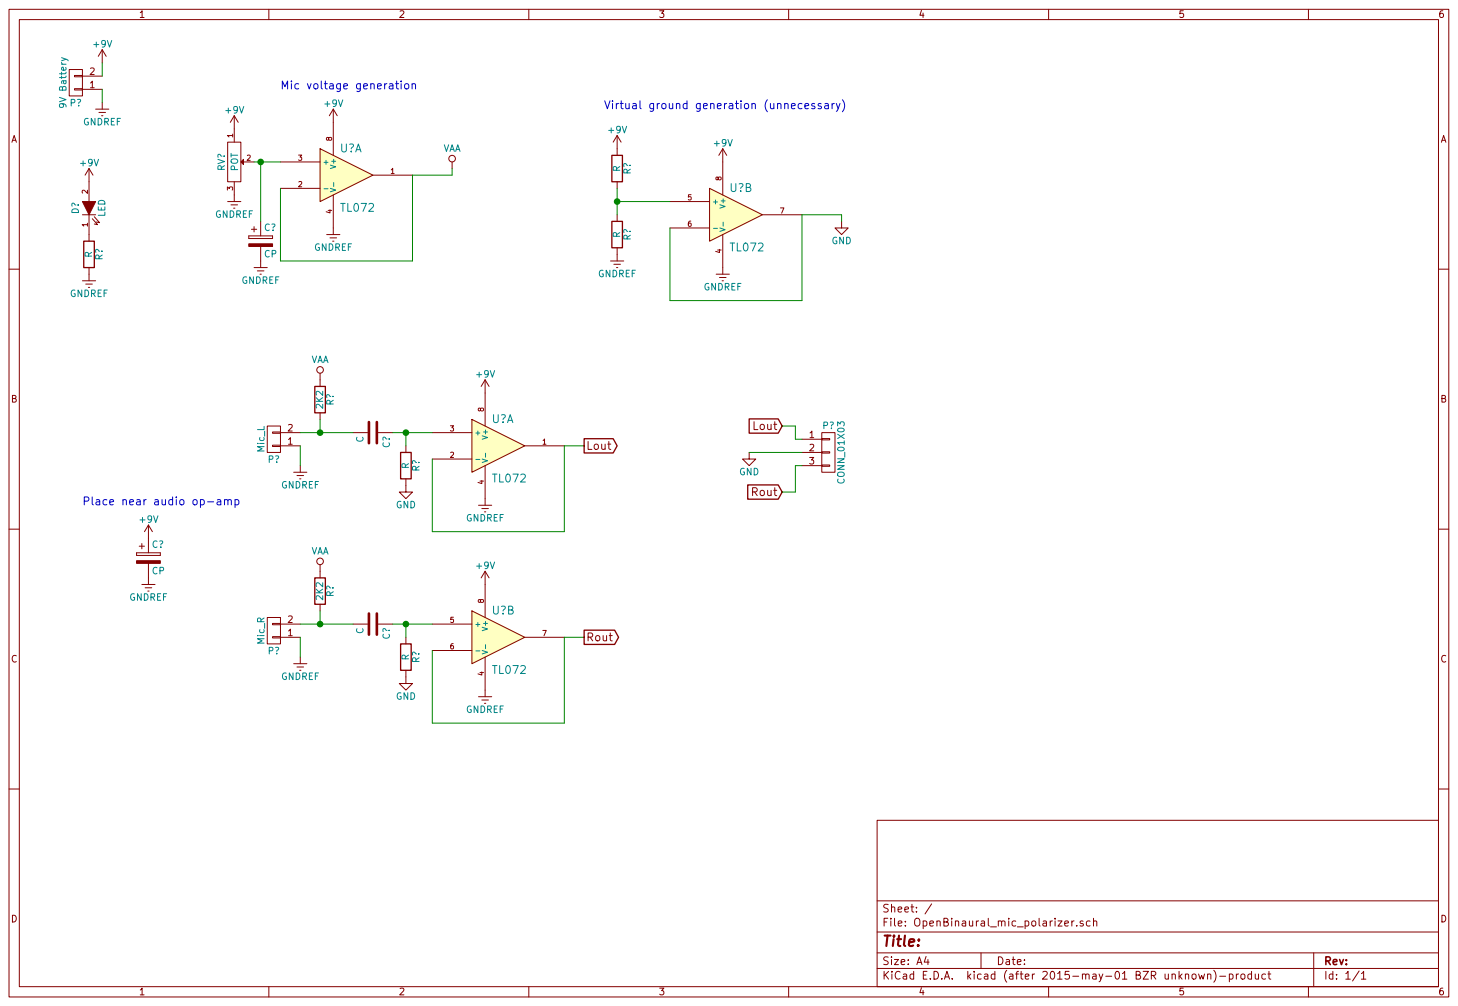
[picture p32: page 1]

+9V GNDREF Virtual ground generation (unnecessary) VAA Mic voltage generation

RR? +9V GNDREF Rout C?CP GNDREF V- 4 V+

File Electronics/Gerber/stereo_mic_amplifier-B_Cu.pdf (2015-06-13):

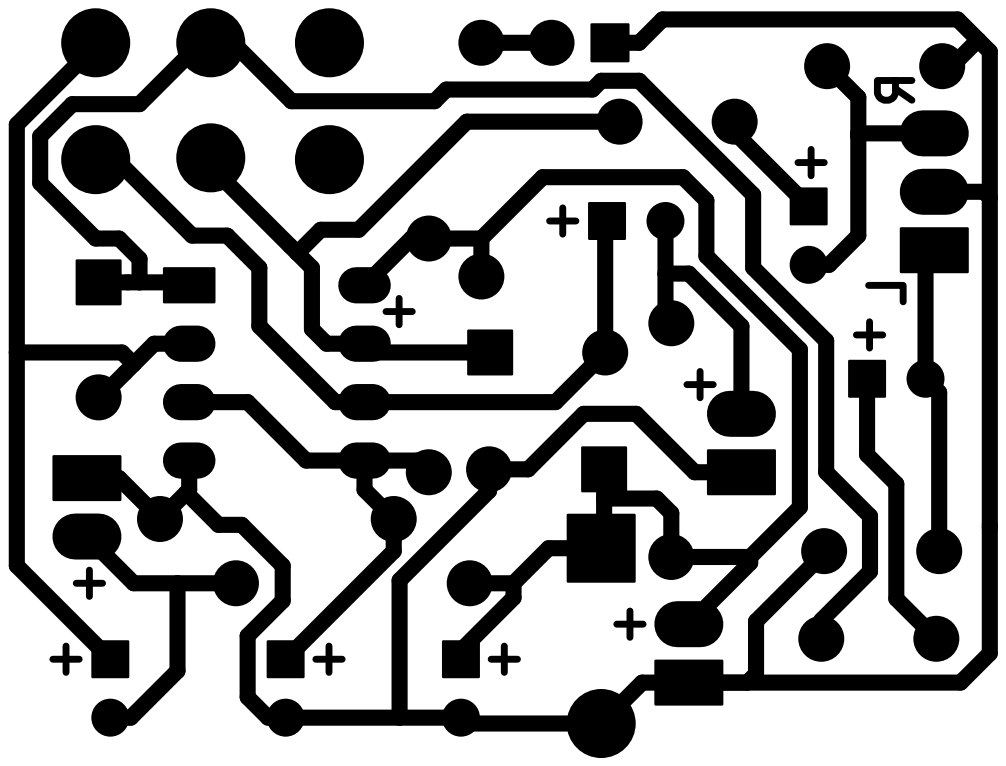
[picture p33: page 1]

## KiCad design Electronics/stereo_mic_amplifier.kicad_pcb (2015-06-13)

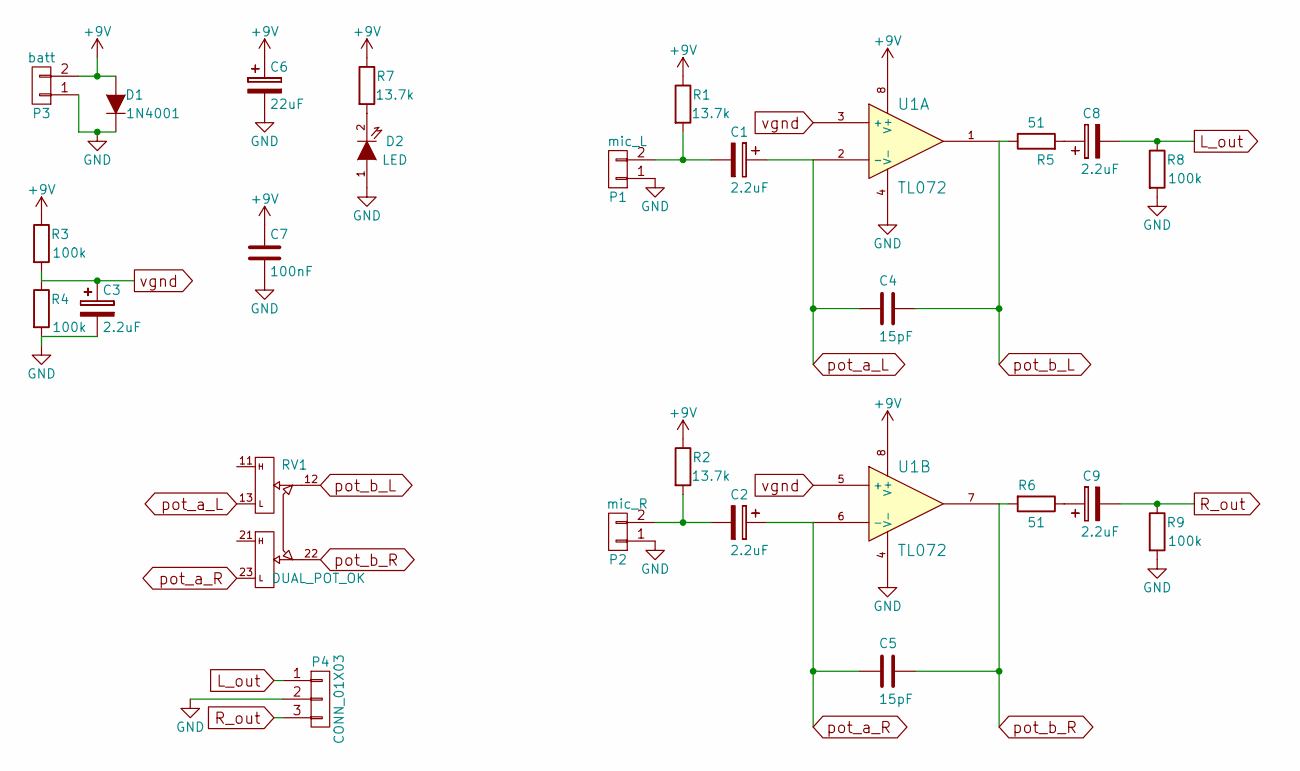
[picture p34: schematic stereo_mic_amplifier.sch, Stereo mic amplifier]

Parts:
C1, C2, C3, C8, C9: 2.2uF; C1V8
C4, C5: 15pF; C_Disc_D7.5_P5
C6: 22uF; C1V8
C7: 100nF; C_Disc_D7.5_P5
D1: 1N4001; D3
D2: LED; LED-5MM
P1: mic_L; Pin_Header_Straight_1x02
P2: mic_R; Pin_Header_Straight_1x02
P3: batt; Pin_Header_Straight_1x02
P4: CONN_01X03; Pin_Header_Straight_1x03
R1, R2, R7: 13.7k; Resistor_Horizontal_RM10mm
R3, R4: 100k; Resistor_Horizontal_RM10mm
R5, R6: 51; Resistor_Vertical_RM5mm
R8, R9: 100k; Resistor_Vertical_RM5mm
RV1: DUAL_POT_OK; Potentiometer_Alps-RK163-double_15mm
U1: TL072; DIP-8__300_ELL

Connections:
+9V: C6.1, C7.1, D1.1 (A), P3.2, R1.1, R2.1, R3.1, R7.1, U1.8 (V+)
GND: C3.2, C6.2, C7.2, D1.2 (K), D2.1 (A), P1.1, P2.1, P3.1, P4.2, R4.2, R8.2, R9.2, U1.4 (V-)
L_out: C8.2, P4.1, R8.1
unnamed: C1.2, P1.2, R1.2
unnamed: C2.2, P2.2, R2.2
unnamed: C8.1, R5.2
unnamed: C9.1, R6.1
unnamed: D2.2 (K), R7.2
R_out: C9.2, P4.3, R9.1
pot_a_L: C1.1, C4.2, RV1.13, U1.2 (-)
pot_a_R: C2.1, C5.2, RV1.23, U1.6 (-)
pot_b_L: C4.1, R5.1, RV1.12, U1.1
pot_b_R: C5.1, R6.2, RV1.22, U1.7
vgnd: C3.1, R3.2, R4.1, U1.3 (+), U1.5 (+)

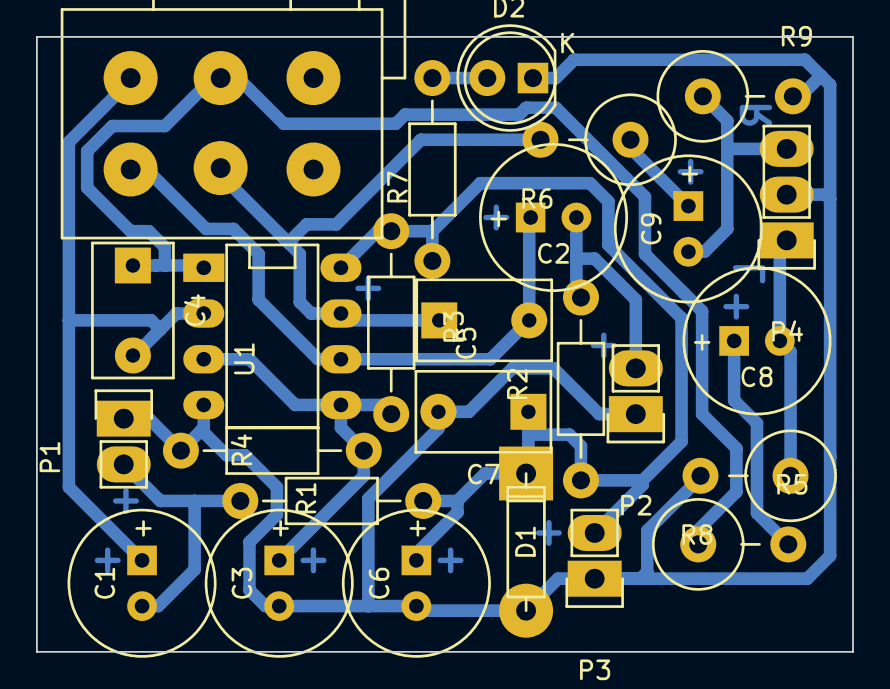
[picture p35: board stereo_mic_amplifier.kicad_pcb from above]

Board: 2 copper layers, 45.3 x 34.2 mm, 26 parts (0 on the bottom side), 14 nets.

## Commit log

2015-05-10 Added L/R files
    [binaural_mic_left.stl, binaural_mic_right.stl]
2015-05-10 Repaired overhang
    [binaural_mic.stl, binaural_mic_assembled.stl, binaural_mic_left.stl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]
2015-05-10 updated left ear
    [binaural_mic_left.stl]
2015-05-10 Updated ear size
    [binaural_mic.scad, binaural_mic_assembled.stl, binaural_mic_right.stl]
2015-05-11 Added bevel for microphone holder
    [binaural_mic.scad, binaural_mic_assembled.stl, binaural_mic_left.stl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]
2015-05-13 Improved ear canal & ear shape
    [binaural_mic.scad, binaural_mic_assembled.stl, binaural_mic_left.stl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]
2015-05-15 Created laser-cuttable wood support
    [binaural_mic.dxf, binaural_mic.scad]
2015-05-16 updated STL
    [binaural_mic_assembled.stl]
2015-05-16 Improved wood supports
    [binaural_mic.dxf, binaural_mic.scad, wood_support.dxf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]
2015-05-17 Added electronics folder
    [OpenBinaural_mic_polarizer.sch]
2015-05-17 Working version of the circuit
    [OpenBinaural_mic_polarizer.sch]
2015-05-17 backed up circuit
    [OpenBinaural_mic_polarizer.sch]
2015-05-18 Simplified polarization circuit
    [OpenBinaural_mic_polarizer.sch]
2015-05-21 Updated electronics folder
    [OpenBinaural_mic_polarizer.sch]
2015-06-06 Added holes for potentiometer, LED & switch
    [binaural_mic.scad, wood_support.dxf, wood_support.stl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]
2015-06-06 Added hole for audio cable strain relief (still need to render other files)
    [binaural_mic.scad, wood_support.dxf]
2015-06-06 Adjusted the dimensions of the wood support
    [binaural_mic.scad, wood_support.dxf, wood_support.stl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]
2015-06-07 Added potentiometer knob
    [potentiometer_knob.scad, potentiometer_knob.stl]
2015-06-09 Improved the design of the potentiometer knob
    [potentiometer_knob.scad, potentiometer_knob.stl]
2015-06-09 Increased tolerance for potentiometer knob. Added some components to the schematic.
    [potentiometer_knob.scad, potentiometer_knob.stl, stereo_mic_amplifier.sch]
2015-06-11 Finished schematic
    [stereo_mic_amplifier.sch]
2015-06-12 Specified footprints
    [stereo_mic_amplifier.kicad_pcb, stereo_mic_amplifier.sch]
2015-06-12 Fixed dual potentiometer pins
    [stereo_mic_amplifier.kicad_pcb, stereo_mic_amplifier.sch]
2015-06-12 Deciding layout
    [stereo_mic_amplifier.kicad_pcb]
2015-06-12 Fixing kicad libraries
    [stereo_mic_amplifier.kicad_pcb]
2015-06-12 Work on the layout
    [stereo_mic_amplifier.kicad_pcb, stereo_mic_amplifier.sch]
2015-06-12 Increased pad sizes & improvements in layout
    [stereo_mic_amplifier.kicad_pcb]
2015-06-13 Layout progress
    [stereo_mic_amplifier.kicad_pcb, stereo_mic_amplifier.sch]
2015-06-13 Finished layout
    [stereo_mic_amplifier.kicad_pcb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]
2015-06-13 Updated gerbers
    [stereo_mic_amplifier-B_Cu.gbr, stereo_mic_amplifier.drl]
2015-06-13 Updated layout & cnc files
    [stereo_mic_amplifier.kicad_pcb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]
2015-06-13 rotated gerber
    [stereo_mic_amplifier.kicad_pcb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]
2015-06-13 Updated readme, plotted schematic, removed previous trials
    [OpenBinaural_mic_polarizer.sch, stereo_mic_amplifier.sch]
2015-06-13 Swapped misplaced capacitor values
    [stereo_mic_amplifier.kicad_pcb]
2015-06-14 Re-arranged electronics directory
    [stereo_mic_amplifier.kicad_pcb, stereo_mic_amplifier.sch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]
2015-07-29 Fixed reversed diodes
    [stereo_mic_amplifier.sch]
2015-07-29 Added image with the schematic
2015-09-28 Updated readme, started assembly instructions
2015-09-28 Added assembly steps
2015-09-28 Added jack connector image, source http://www.akitarescueoftulsa.com/balanced-audio-wiring-diagram/
2015-10-27 Backup of version with self-threaded tripod mount
    [wood_support.dxf, wood_support.stl, wood_support_assembled.stl]
2015-10-27 Added version with metal insert tripod mount
    [binaural_mic.scad, wood_support.dxf, wood_support_assembled.stl]
2015-10-30 Increased diameter of tripod metal insert
    [binaural_mic.scad, wood_support_assembled.stl]
2015-11-09 Rotated ears vertically, and increased ear support diameter, ear size, microphone diameter, and tripod mount diameter
    [binaural_mic.scad, binaural_mic_left.stl, binaural_mic_right.stl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]
2015-11-09 Added tripod mount image
2015-11-10 Gcode pass to Z-0.15mm
2015-11-26 Updated tolerance for the tripod metal thread insert
    [binaural_mic.scad, wood_support_assembled.stl]
2023-12-31 Included DOI and Bibtex citation references, notes and simplified frame
    [binaural_mic_simplified.scad, wood_support_assembled_simplified.stl]
